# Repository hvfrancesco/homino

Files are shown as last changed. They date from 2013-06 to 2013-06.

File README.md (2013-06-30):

Homino
======

What is Homino?
---------------

Homino is a diy Arduino Duemilanove/Uno compatible board with some moloko vellocet addition
(e.g. featuring on-board 433Mhz RF transceiver for experiments on home-automation and microcontroller communication).
Homino is an open-hardware project by HVA (http://www.hv-a.com)

The board is based on Arduino open-hardware design, but revised in order to be made using a single-sided copper board and low-tech techniques like toner-transfer etching.
The connectors in Homino are arduino shields compatible, but the board comes in Altoids tin can format, so you can have the mints while soldering all those little components.

How does Homino compare to Arduino?
-----------------------------------

Homino replicates almost all the features of Atmega328 based Arduino, with a few design limitations:

- No on-board usb-to-ttl, you will need an external usb-ttl cable to program it or a serial port adapter that can handle RS232 level switching (however auto-reset works flawlessly)
- No ISP connector

There is fortunately some nice additions too:

- Selectable 5V/3.3V operation mode (through an old style jumper, we feared a slide switch could be more dangerous)
- On-board RF communication based on low-cost 433Mhz radio modules like the ones from SeeedStudio, allowing the interoperability with current low-cost 433 MHz remote controlled devices. Homino will most likely work with all 433Mhz popular power outlet sockets.
Communication between several Homino boards or any other 433Mhz RF enabled microcontroller is also very easily done through VirtualWire library.

How do I build Homino?
----------------------

Homino is designed to be built on a homemade custom produced pcb using single sided boards.
We successfully built several boards using tone-transfer method using a photocopier and common light magazine coated paper, you can use transparency film, but the magazine solution proved to be the most reliable and cheapest in our experience.
Homino board is rather dense and has some thin routes and small gaps between them, so it is not the easiest design to use with tone-transfer based etching, but if you're careful it works very well.

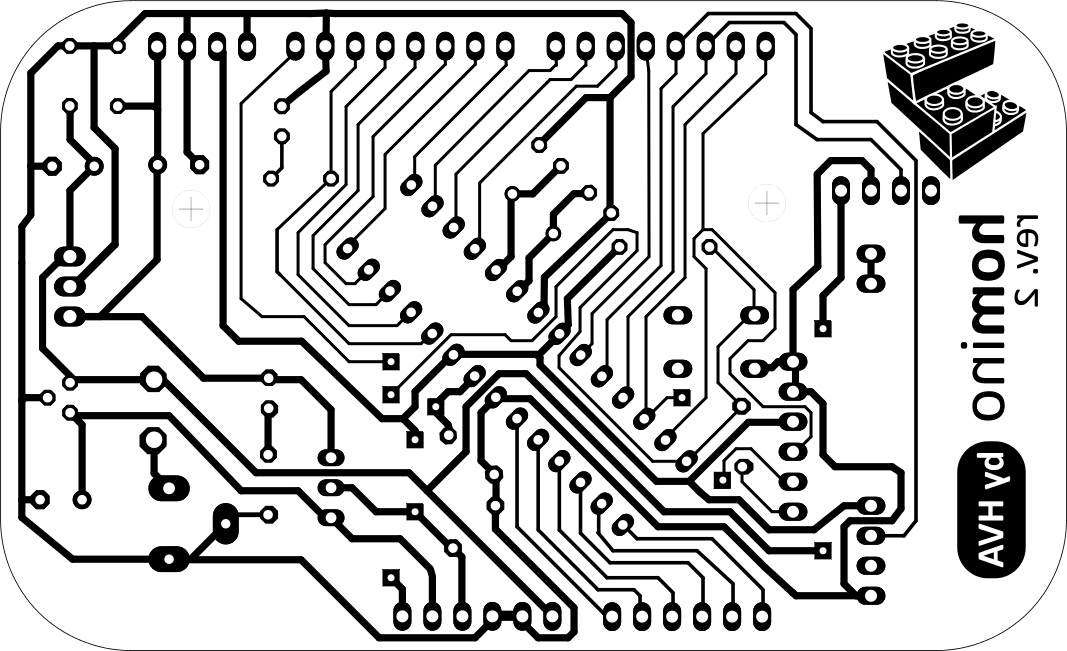
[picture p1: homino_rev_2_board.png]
board image for tone transfer


List of components:

- PCB single sided board (you can cut 3 Homino boards from a 160x100 sheet)
- 1 x Atmega328 MCU (use Atmega328P-PU for lower power consumption, Atmega328-PU will work fine anyway)
- 1 x 28 way DIL socket (optional but useful if you plan to remove or change the Atmega chip)
- 3 x 47uF capacitors
- 5 x 0,1 uF ceramic capacitors
- 2 x 22 pF ceramic capacitors
- 1 x 5V voltage regulator (7805 in TO-220 case)
- 1 x 3.3 V voltage regulator (LP2950 in TO-92 case)
- 1 x N4001 diode
- 2 x 1k resistor
- 1 x 10k resistor
- 2 x leds (using a blue led for power and a red one linked to digital pin13)
- 1 x 16Mhz crystal (a cheaper 16
Mhz ceramic resonator can be used, you could choose a 3-pin resonator and in that case you can probably omit the 22pF capacitors, but we like the crystal better)
- 1 power jack (optional)
- female pin sockets
- 1 x 6 way male pin header
- 1 x 3 way male pin header with jumper
- 1 x button for reset
- RF transmitter and receiver modules

The cost of the components is about 9,5 euros when bought in very small quantities from online distributors like Farnell or RS, if you buy larger quantities or have cheaper providers, the total cost can be quite lower. RF modules from SeeedStudio cost $4,9.
Ideal cost including RF modules should be around 12 US$.
You can buy Atmega328 chip already programmed with Arduino bootloader from several distributors or Arduino online store, but if you already own an Arduino or some kind of AVR programmer you can buy bare 328 chip and save a few euros. Burning the bootloader to an Atmega using another Arduino as ISP programmer, even if you are new to Arduino world, is a piece of cake if you follow this tutorial:
http://arduino.cc/en/Tutorial/ArduinoToBreadboard

The following image is a label you can simply print on self-adhesive paper and stick on top of your Homino board before soldering the components.
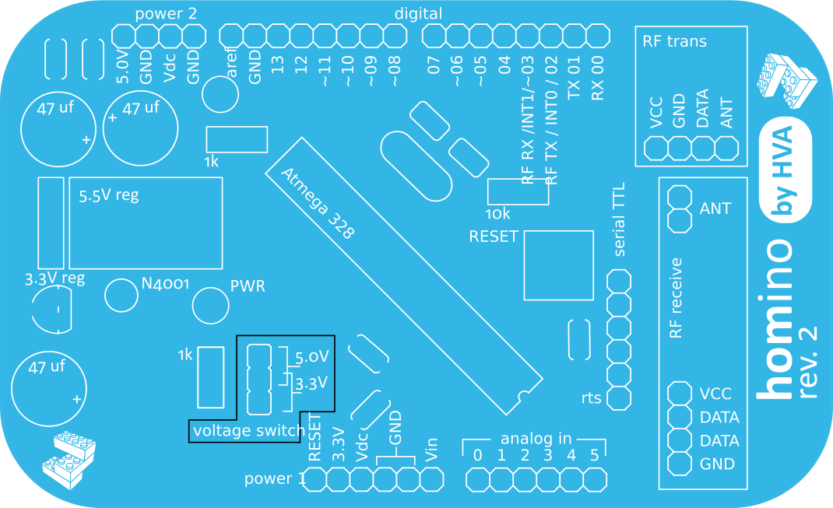
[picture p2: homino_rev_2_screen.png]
board image for top label


Useful links
------------

Arduino libraries for RF projects
- http://code.google.com/p/rc-switch/
- http://www.airspayce.com/mikem/arduino/

Low-cost RF modules compatible with Homino
- http://www.seeedstudio.com/depot/433mhz-rf-link-kit-p-127.html?cPath=19_22

Credits
-------

Homino is obviously Open Hardware, and all the files are distributed under a
<a rel="license" href="http://creativecommons.org/licenses/by-nc-sa/3.0/">Creative Commons Attribution-NonCommercial-ShareAlike 3.0 Unported License</a>
.

HVA lego-logo is property of 'HVA - hermanitos verdes architetti' (http://www.hv-a.com) and shouldn't be used without permission.

Homino is inspired and based on other Arduino compatible projects, for example:

http://hacks.ayars.org/2013/05/ayrduino-single-sided-arduino-clone.html
http://vonkonow.com/wordpress/2012/10/nanino-the-diy-friendly-arduino

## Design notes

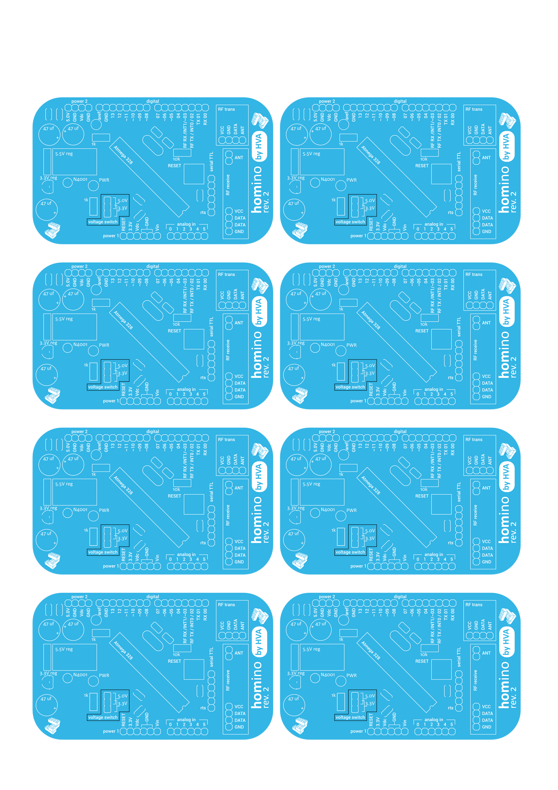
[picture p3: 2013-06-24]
Homino_v2_mint_temp_screen_2.png

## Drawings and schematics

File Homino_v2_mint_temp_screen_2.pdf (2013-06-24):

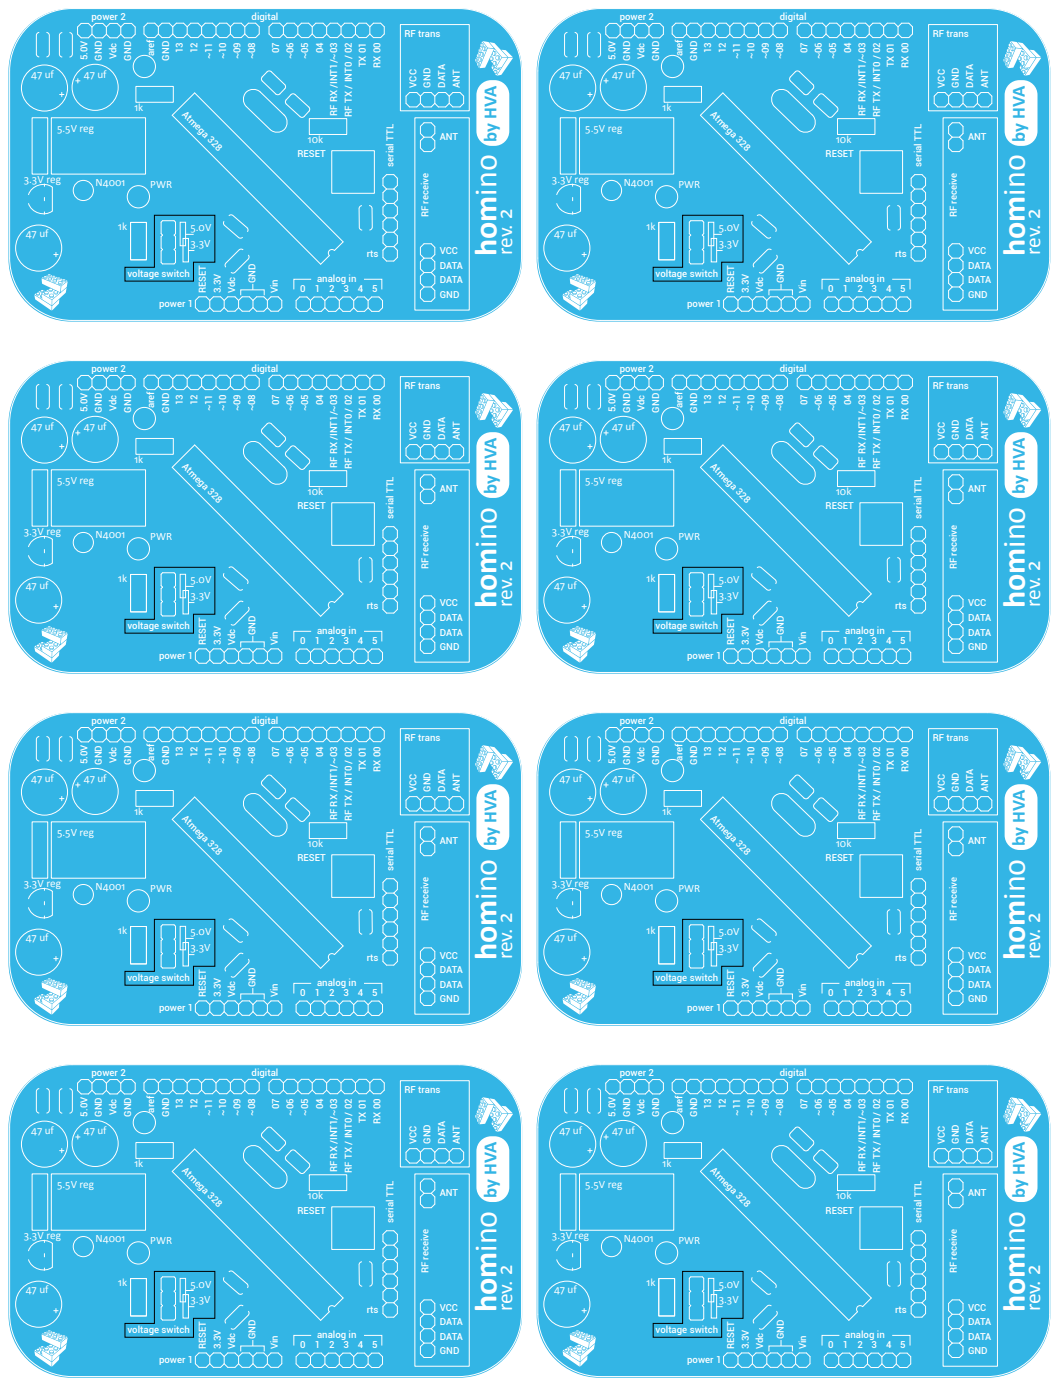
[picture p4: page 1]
homino; rev. 2; by HVA; GND; Vdc; aref; digital; RF RX /INT1/~03; RF TX / INT0 / 02; VCC; DATA; ANT; RF trans; PWR; 5.5V reg; 3.3V reg; 3.3VRESET; Atmega 328; RESET; RF receive; serial TTL; rts; Vin; analog in 1 2 3 4 5; power 2; power 1; voltage switch

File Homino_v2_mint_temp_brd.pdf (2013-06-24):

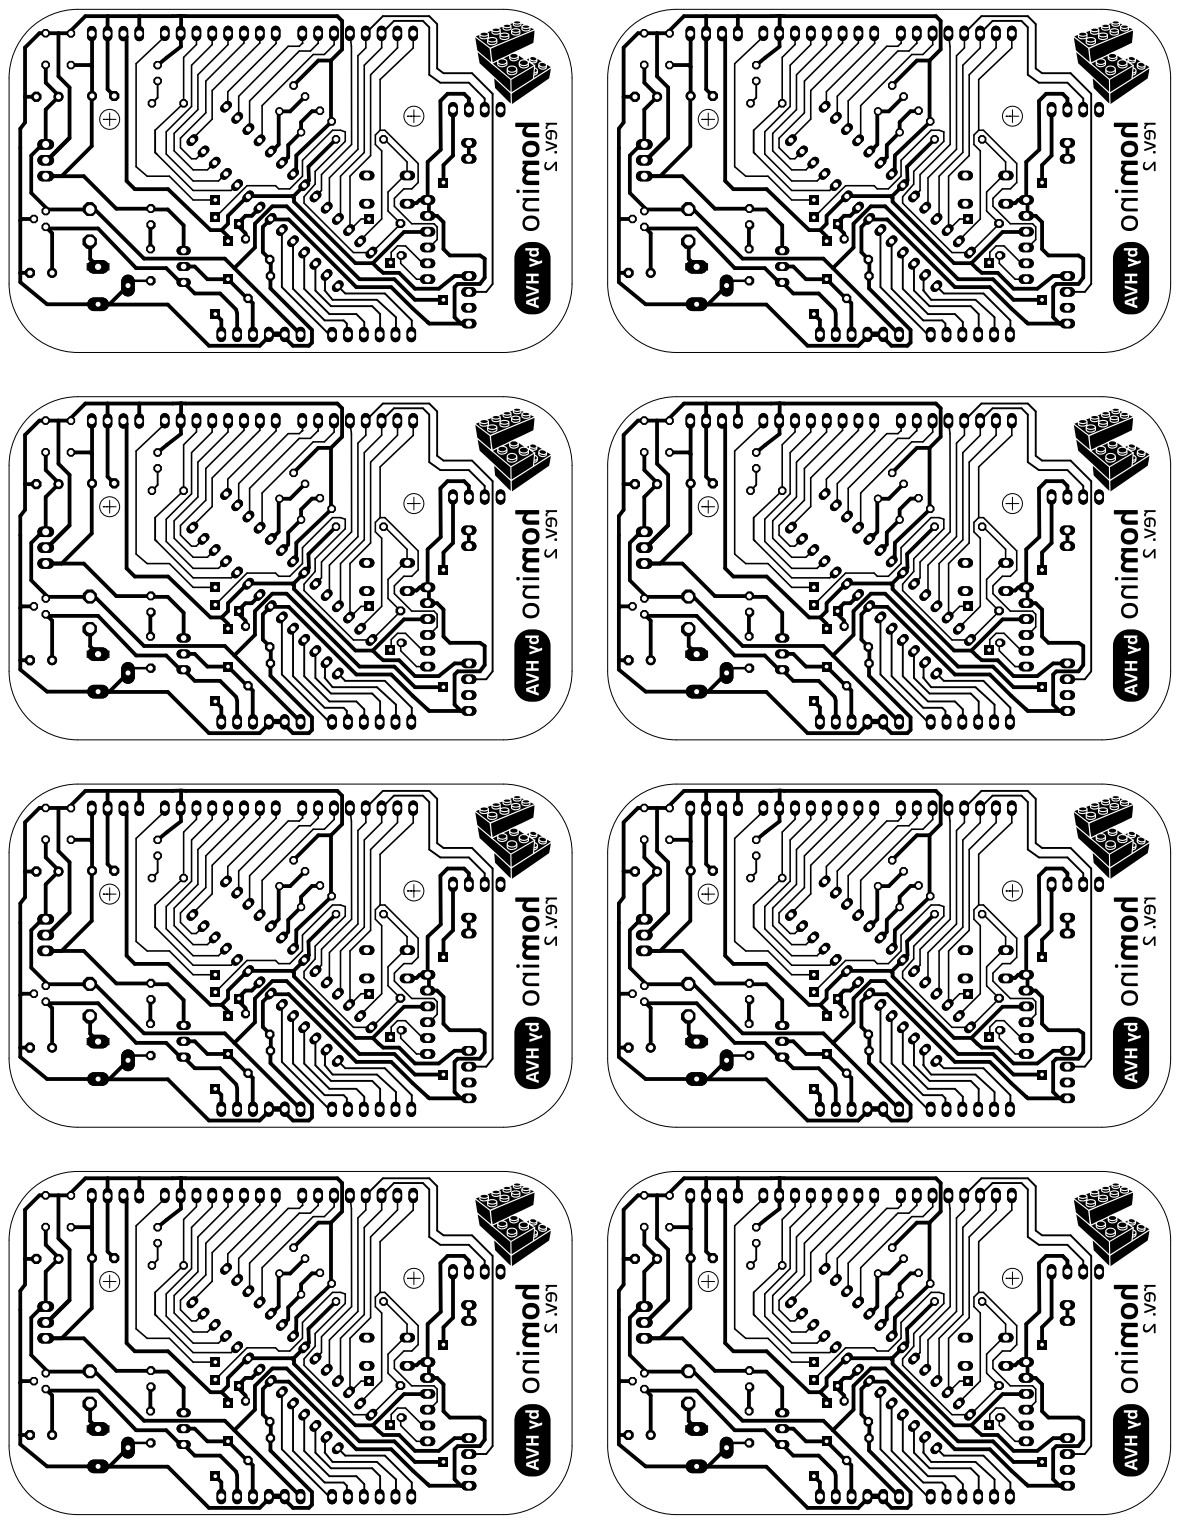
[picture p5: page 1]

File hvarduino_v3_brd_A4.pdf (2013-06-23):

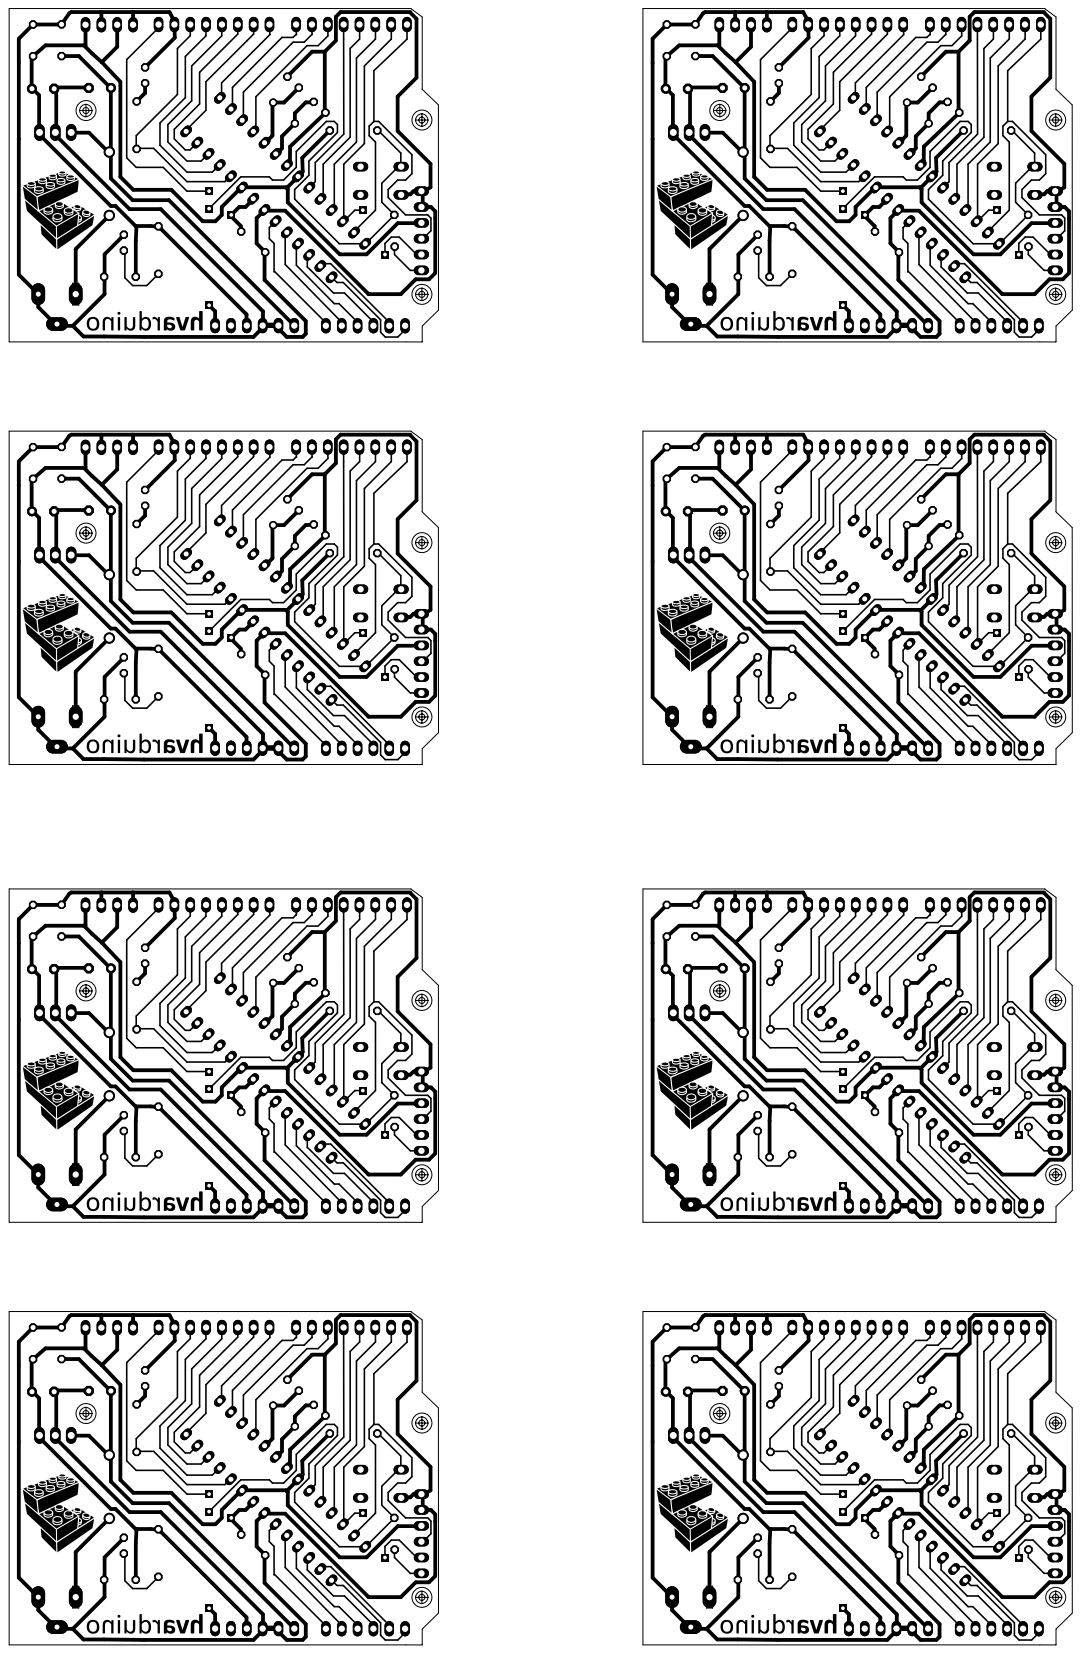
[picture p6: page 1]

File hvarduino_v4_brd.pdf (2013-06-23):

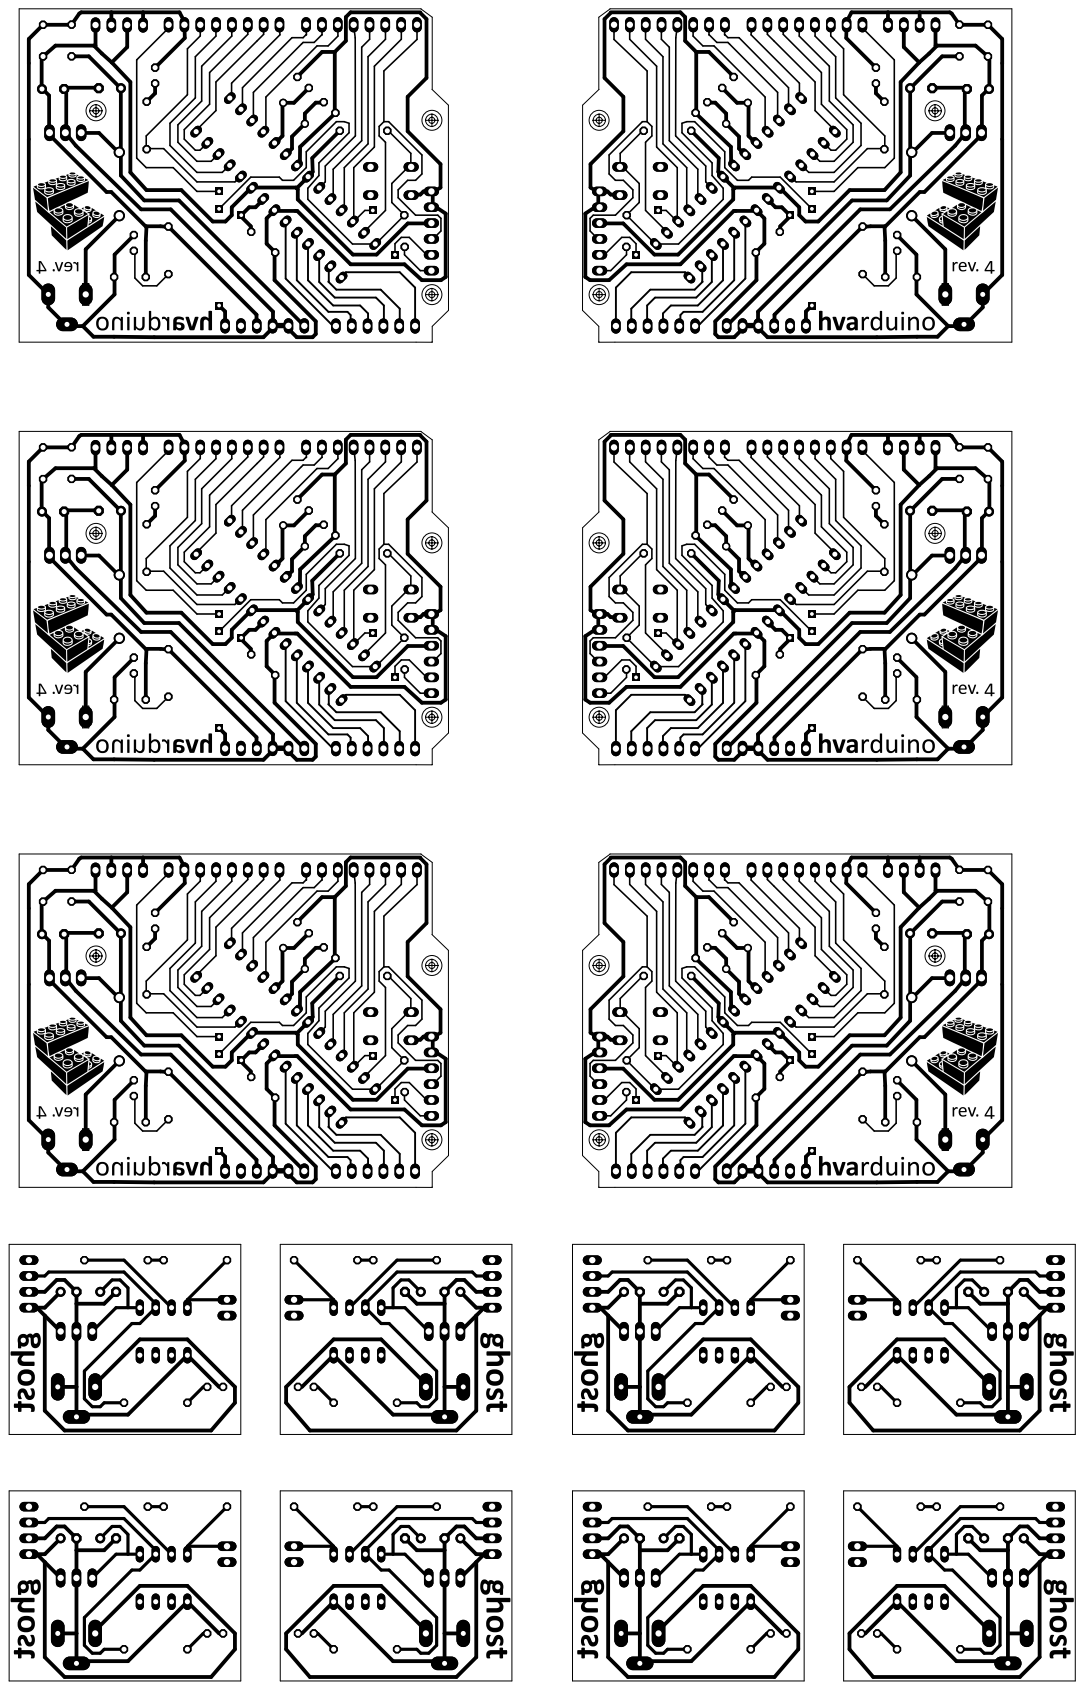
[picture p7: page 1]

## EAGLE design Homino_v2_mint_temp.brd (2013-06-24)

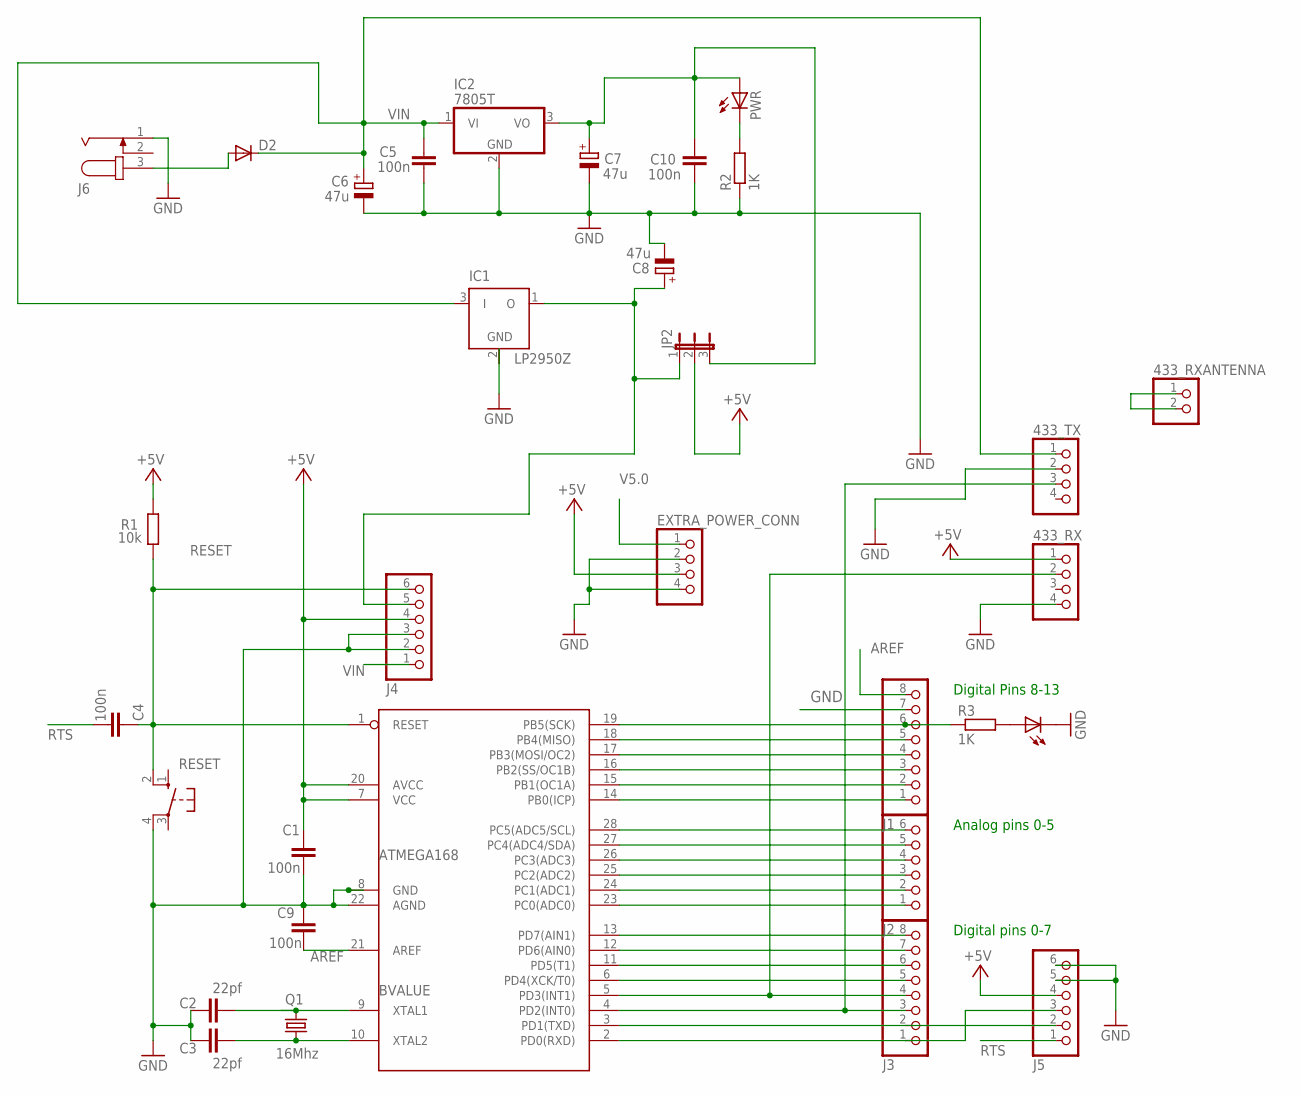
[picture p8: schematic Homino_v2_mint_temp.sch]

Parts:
433_RX, 433_TX: PINHD-1X4; 1X04
433_RXANTENNA: PINHD-1X2; 1X02
BVALUE: ATMEGA168; DIL28-3
C1, C4, C5, C9, C10: 100n; C050-024X044
C2, C3: 22pf; C025-024X044
C6, C7, C8: 47u; E3,5-8
D2: DIODE-C1702-05; C1702-05
EXTRA_POWER_CONN: PINHD-1X4; 1X04
IC1: LP2950Z; TO92
IC2: 7805T; TO220H
J1, J3: PINHD-1X8; 1X08
J2, J4, J5: PINHD-1X6; 1X06
J6: JACK-PLUG0; SPC4077
JP2: JP2E; JP2
P13: LED3MM
PWR: LED3MM
Q1: 16Mhz; HC49U-V
R1: 10k; 0204/7
R2, R3: 1K; 0204/5
RESET: 10-XX; B3F-10XX

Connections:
AREF: BVALUE.21 (AREF), C9.1, J1.8
DCV: 433_RX.1, BVALUE.7 (VCC), BVALUE.20 (AVCC), C1.1, EXTRA_POWER_CONN.3, J4.4, J5.4, JP2.2, R1.2
GND: 433_RX.4, 433_TX.2, BVALUE.8 (GND), BVALUE.22 (AGND), C1.2, C2.1, C3.1, C5.1, C6.-, C7.-, C8.-, C9.2, C10.1, EXTRA_POWER_CONN.2, EXTRA_POWER_CONN.4, IC1.2 (GND), IC2.2 (GND), J1.7, J4.2, J4.3, J5.5, J5.6, J6.1, P13.K (C), R2.1, RESET.4 (P1)
unnamed: BVALUE.2 (PD0(RXD)), J3.1, J5.3
unnamed: BVALUE.15 (PB1(OC1A)), J1.2
unnamed: PWR.K (C), R2.2
unnamed: D2.A, J6.3
unnamed: BVALUE.9 (XTAL1), C2.2, Q1.2
unnamed: P13.A, R3.2
unnamed: 433_TX.3, BVALUE.4 (PD2(INT0)), J3.3
unnamed: 433_RX.2, BVALUE.5 (PD3(INT1)), J3.4
unnamed: BVALUE.6 (PD4(XCK/T0)), J3.5
unnamed: BVALUE.11 (PD5(T1)), J3.6
unnamed: BVALUE.12 (PD6(AIN0)), J3.7
unnamed: BVALUE.13 (PD7(AIN1)), J3.8
unnamed: BVALUE.23 (PC0(ADC0)), J2.1
unnamed: BVALUE.24 (PC1(ADC1)), J2.2
unnamed: BVALUE.25 (PC2(ADC2)), J2.3
unnamed: BVALUE.26 (PC3(ADC3)), J2.4
unnamed: BVALUE.27 (PC4(ADC4/SDA)), J2.5
unnamed: BVALUE.28 (PC5(ADC5/SCL)), J2.6
unnamed: BVALUE.3 (PD1(TXD)), J3.2, J5.2
unnamed: BVALUE.16 (PB2(SS/OC1B)), J1.3
unnamed: 433_RXANTENNA.1, 433_RXANTENNA.2
unnamed: BVALUE.18 (PB4(MISO)), J1.5
unnamed: BVALUE.14 (PB0(ICP)), J1.1
unnamed: BVALUE.10 (XTAL2), C3.2, Q1.1
unnamed: BVALUE.17 (PB3(MOSI/OC2)), J1.4
RESET: BVALUE.1 (RESET), C4.1, J4.6, R1.1, RESET.2 (S1)
RTS: C4.2, J5.1
SCK: BVALUE.19 (PB5(SCK)), J1.6, R3.1
V3.3: C8.+, IC1.1 (O), J4.5, JP2.1
V5.0: C7.+, C10.2, EXTRA_POWER_CONN.1, IC2.3 (VO), JP2.3, PWR.A
VIN: 433_TX.1, C5.2, C6.+, D2.C, IC1.3 (I), IC2.1 (VI), J4.1

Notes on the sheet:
Analog pins 0-5
Digital Pins 8-13
Digital pins 0-7

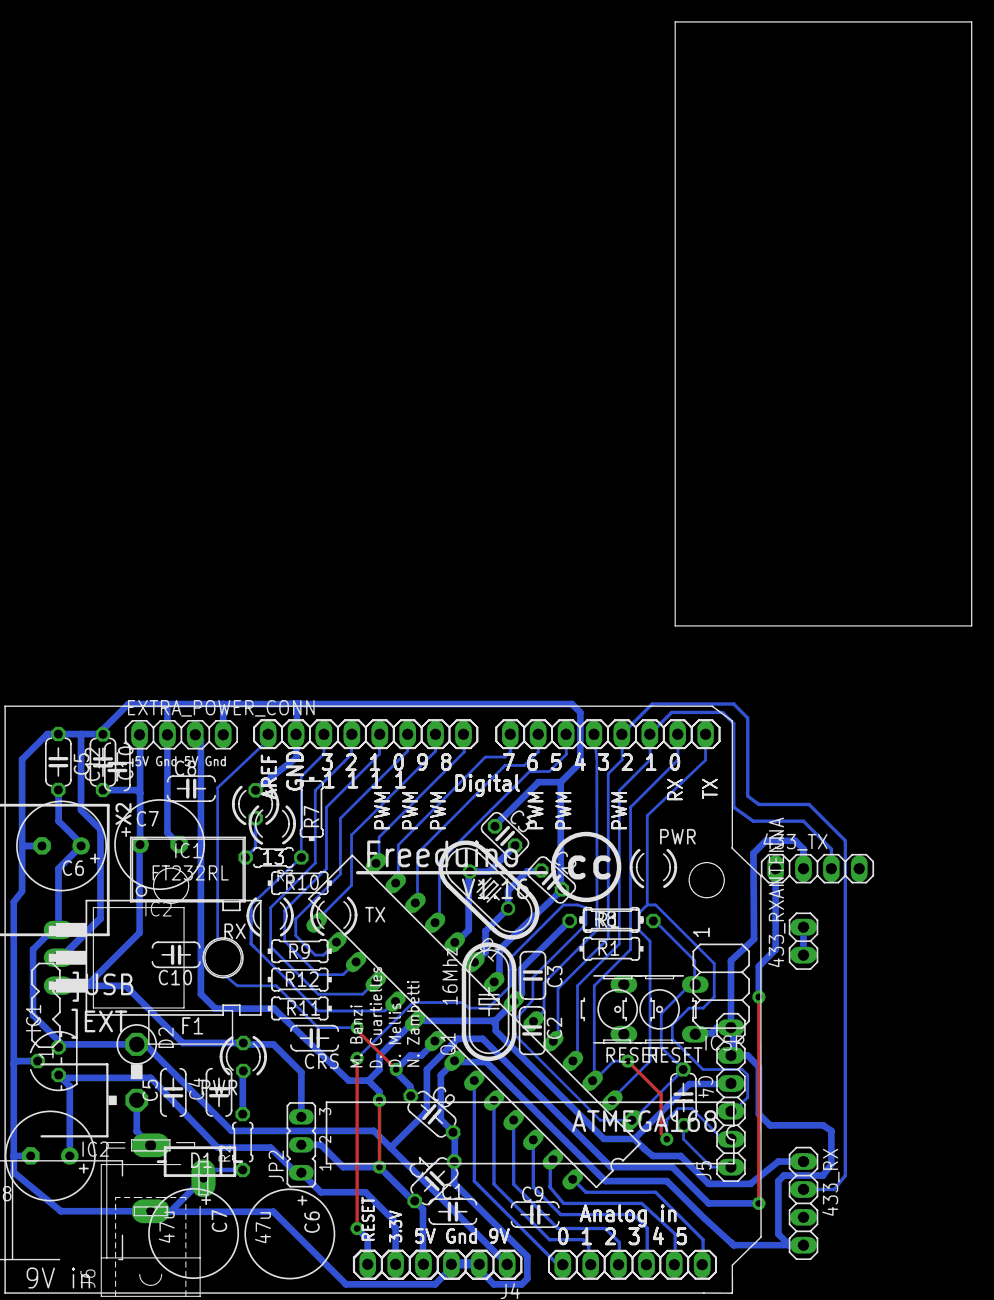
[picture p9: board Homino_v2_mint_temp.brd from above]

Board: 2 copper layers, 32 parts (0 on the bottom side), 34 nets.

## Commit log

2013-06-23 testing different layout
    [Homino_v2_mint_temp.brd, Homino_v2_mint_temp.sch]
2013-06-23 got rid of a jumper on V5.0 line, but maybe there is now a clearance problem with Vin through the voltage selection pin header
    [Homino_v2_mint_temp.brd]
2013-06-24 rev.2 of board in beta status
    [Homino_v2_mint_temp.brd]
2013-06-29 cleaned tree
    [Ayrduino_v5_mint.brd, Ayrduino_v5_mint.sch, Ayrduino_v6_mint.brd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]
2013-06-29 added single board images for tone tranfer and label print
2013-06-29 started adding information about board making
2013-06-30 minor changes
    [usb_to_uart.brd, usb_to_uart.sch]

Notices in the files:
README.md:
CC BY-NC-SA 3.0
